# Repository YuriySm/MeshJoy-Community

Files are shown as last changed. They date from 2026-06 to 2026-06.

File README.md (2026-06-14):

# MeshJoy

*[🇺🇦 Ukrainian / Українська версія](README.uk.md).*

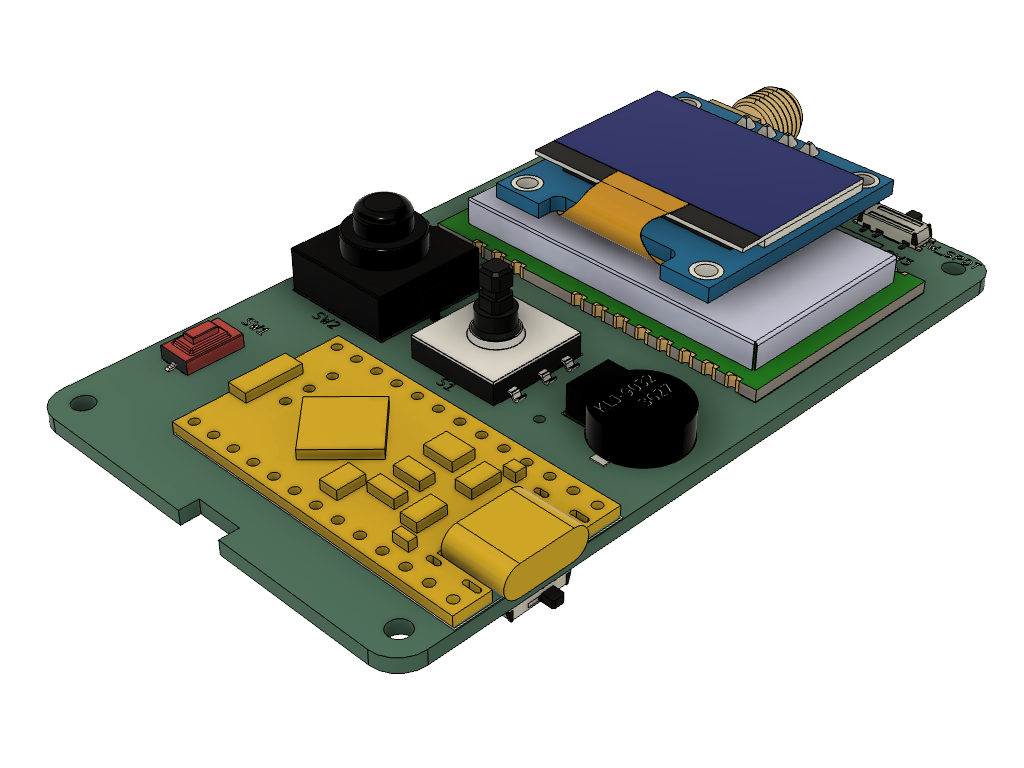
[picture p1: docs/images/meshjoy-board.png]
MeshJoy board


A portable **Meshtastic / Meshcore** radio device with up to **1 W LoRa** output power and **3–4 days** of battery life.

Built for hikers, radio amateurs, and anyone who needs communication without the internet.

> Status: v0.2.2 assembled and tested.

## Features

- **Joystick + OLED screen** — convenient menu navigation via a 4-way joystick with push-to-select.
- **Physical power button** — combined mechanical/electronic power control.
- **GPS switch** — GPS can be fully disabled in software *or* with a hardware switch on the case.
- **GPS navigation** (optional) — Ebyte E108-GN02D receiver reports coordinates at configurable intervals to the public Meshtastic network or only to selected contacts. The receiver sleeps between intervals to save power.
- **Buzzer** — sound notifier pre-installed on the board.
- **Expandable** — optional vibration motor; accessible reset button and visible status LEDs without opening the case.
- **Built-in charger** — charging managed by the microcontroller; over-discharge protection via the battery BMS.

## Battery options

| Battery | Capacity | GPS |
|---|---|---|
| LiPo 103450 | 2000 mAh | Yes |
| Li-Ion 18650 | 3400 mAh | Yes |
| Li-Ion 18650 ×2 | 6800 mAh | No |

## Specifications

| | |
|---|---|
| LoRa radio | Ebyte E22-400M30S, 1 W |
| Microcontroller | ProMicro nRF52840 |
| GPS | Yes (optional) |
| Bluetooth | Yes (~2 m range) |
| Wi-Fi | No |
| Battery | 2000 mAh (2400–6800 mAh) |
| Charge current | ~300 mA |
| Battery life | 3–4 days (no GPS, 2 Ah battery) |
| Charge time | ~7 hours (2 Ah battery) |
| Water resistance | None |
| Size | 49 × 96 × 27 mm (W × H × D) |

## Technical notes

- **Processor:** nRF52840 (ProMicro / SuperMini clone) — low-power, Bluetooth, no Wi-Fi. Built-in LiPo charge controller and 2 LEDs. Reset button broken out on the main board.
- **LoRa:** Ebyte E22-400M30S, 1 W @ 433 MHz. At 5 V it reliably delivers 1–1.2 W.
- **Antenna connector:** SMA female mounted parallel to the board surface — easier to solder and to fit in a small case.
- **Power:** Runs from a 1S (3.7 V) battery or USB-C. An XL6380 boost converter supplies 5 V for the LoRa module. Peak draw during transmit is up to ~1.5 A; average consumption with a test transmission every 5 min was ~65 mW.
- **Power switch:** Combined mechanical/electronic — a physical button drives a MOSFET that switches battery current (a plain micro-switch can't handle the ~1.5 A peak).
- **Joystick:** 4 positions + press; soldered as SMD. The device name comes from "Mesh" + "joystick".
- **Screen:** Standard 0.96" OLED (GND-VCC pinout).
- **External device control:** 2 power MOSFETs switch ground — one for the buzzer, one broken out for a vibration motor or GPS control. A slide switch also cuts +5 V for low-power peripherals (e.g. fully powering off GPS).
- **Board:** Custom-designed, using the standard `nrf52_promicro_diy_tcxo` Meshtastic pinout.

## Enclosure

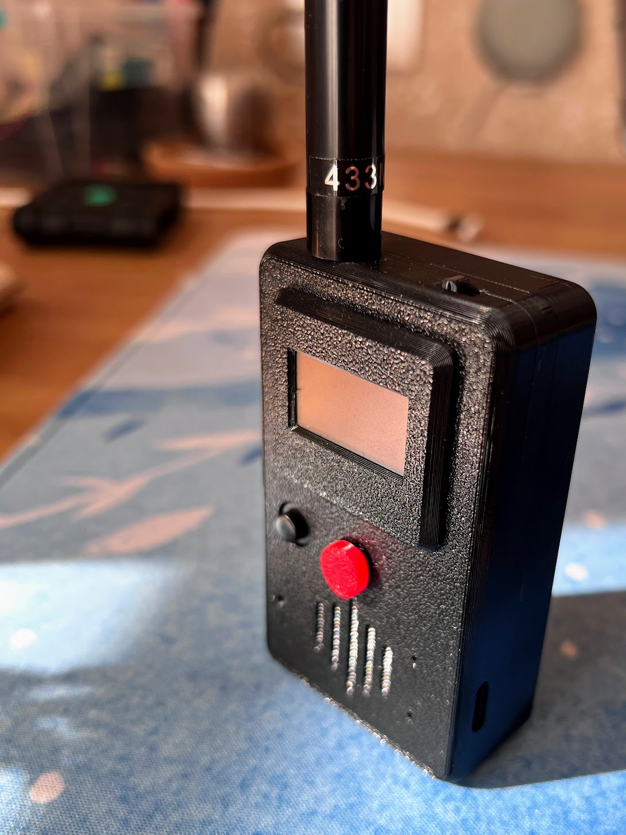
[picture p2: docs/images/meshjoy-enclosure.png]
MeshJoy enclosure


The case was designed from scratch in Fusion 360 and will be **free to download and modify**. It is optimized for fast, support-free 3D printing (PETG). The screen bezel snaps into the top cover without glue; halves are joined with M2 screws (no nuts) and the board is held by integrated standoffs. Mounting for the GPS module is included.

## Links

- Website: https://meshjoy.com.ua/
- Technical details: https://meshjoy.com.ua/technical-details/
- Telegram discussion group: https://t.me/MeshJoy
- Contact the author: https://t.me/Yura_e2c77f35

## License

These materials are licensed under [CC BY-NC-SA 4.0](https://creativecommons.org/licenses/by-nc-sa/4.0/) (Attribution — NonCommercial — ShareAlike).

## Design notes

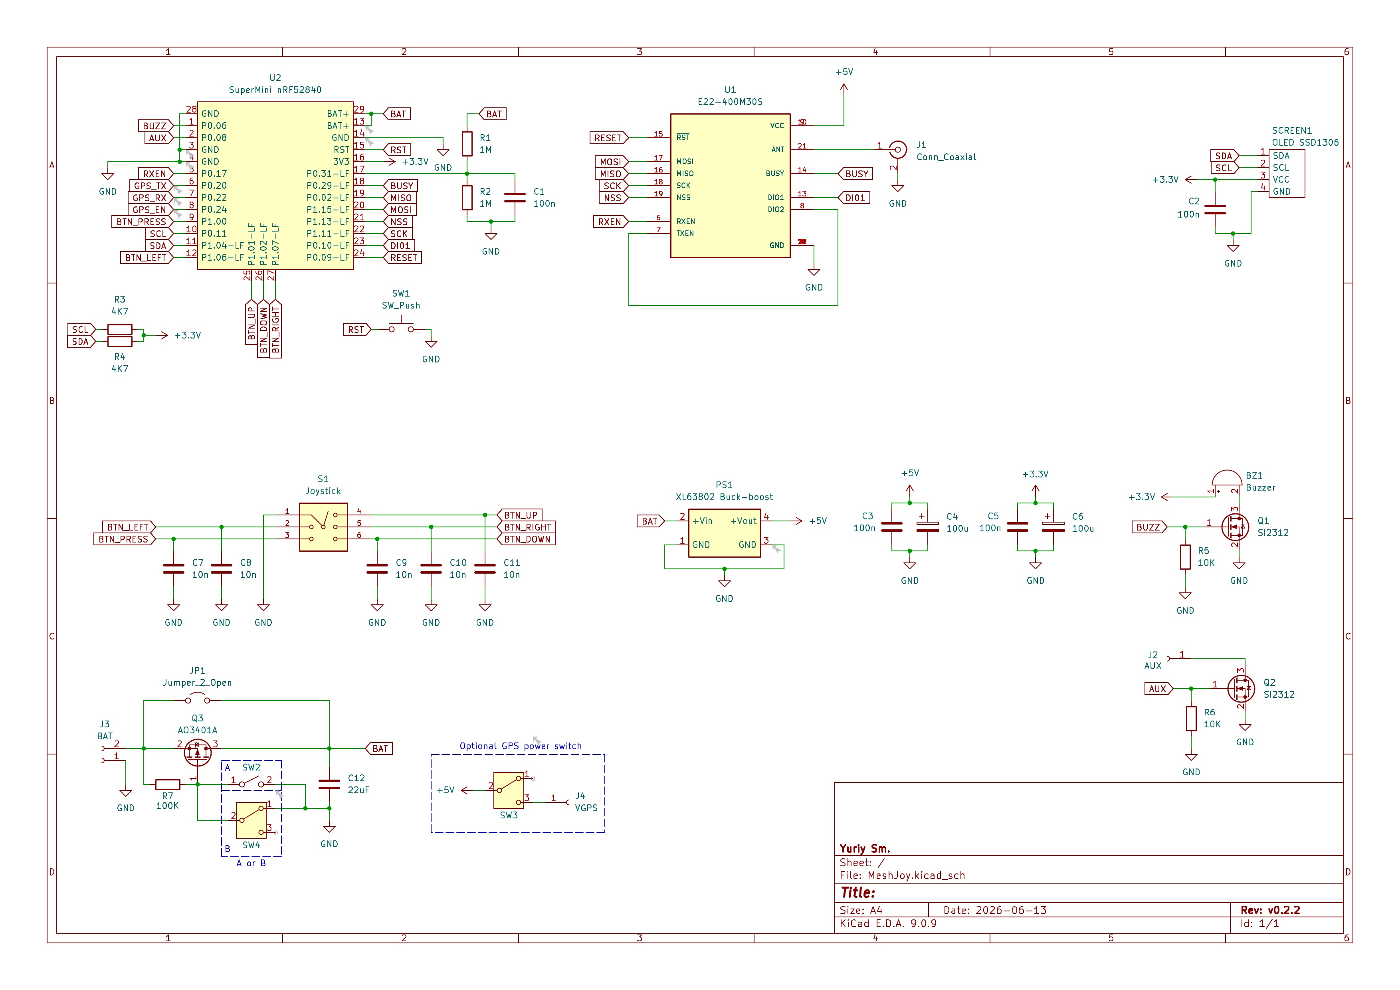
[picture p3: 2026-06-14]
schematic/MeshJoy-v0.2.2-Schematic.png

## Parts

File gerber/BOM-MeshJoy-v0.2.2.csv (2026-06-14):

Comment | Designator | Footprint | LCSC | Quantity
100K | R7 | R_0603_1608Metric_Pad0.98x0.95mm_HandSolder | C25803 | 1
100n | C1,C2,C3,C5 | C_0603_1608Metric_Pad1.08x0.95mm_HandSolder | C14663 | 4
100u | C4,C6 | CP_EIA-3528-15_AVX-H_HandSolder | C16133 | 2
10K | R5,R6 | R_0603_1608Metric_Pad0.98x0.95mm_HandSolder | C25804 | 2
10n | C10,C11,C7,C8,C9 | C_0603_1608Metric_Pad1.08x0.95mm_HandSolder | C57112 | 5
1M | R1,R2 | R_0603_1608Metric_Pad0.98x0.95mm_HandSolder | C22935 | 2
22uF | C12 | C_0603_1608Metric_Pad1.08x0.95mm_HandSolder | C59461 | 1
4K7 | R3,R4 | R_0603_1608Metric_Pad0.98x0.95mm_HandSolder | C23162 | 2
AO3401A | Q3 | SOT-23 | C15127 | 1
SI2312 | Q1,Q2 | SOT-23 | C20917 | 2
E22-400M30S | U1 | XCVR_E22-900M30S_manual_solder |  | 1
OLED SSD1306 | SCREEN1 | SSD1306 |  | 1
SW_Push | SW1 | SW_3x4x2_SMD |  | 1
SW_SPST | SW2 | button_12x12 |  | 1
Joystick | S1 | 5_Way_Switch_10mm |  | 1
SuperMini nRF52840 | U2 | SuperMini_nRF52840_AH_USBup |  | 1
ANT | J1 | SMA_Samtec_SMA-J-P-H-ST-EM1_EdgeMount |  | 1
Buzzer | BZ1 | Buzzer_9032 |  | 1
XL63802 Buck-boost | PS1 | XL63802-Buck-boost |  | 1
BAT | J3 | JST_PH_S2B-PH-K_1x02_P2.00mm_Horizontal |  | 1
-VAUX | J2 | PinHeader_1x01_P2.54mm_Vertical |  | 1
+VGPS | J4 | Pin_D0.7mm_L6.5mm_W1.8mm_FlatFork |  | 1
AUX | SW3 | SW_SPDT_PCM12 |  | 1
PWR | SW4 | SW_SPDT_PCM12 |  | 1
Jumper_2_Open | JP1 | SolderJumper-2_P1.3mm_Open_Pad1.0x1.5mm |  | 1

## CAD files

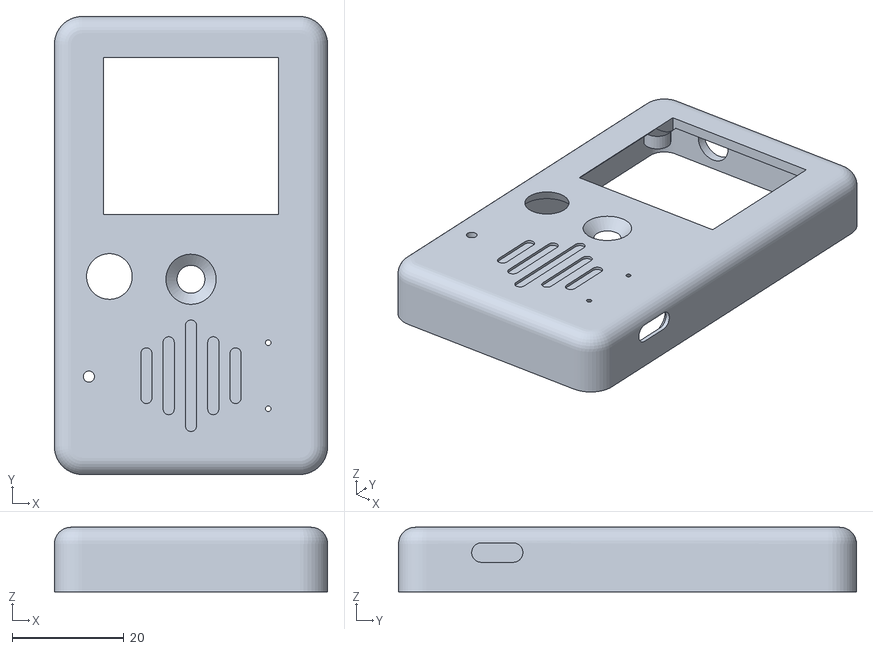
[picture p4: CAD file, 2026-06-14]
enclosure/meshjoy-v02-top-case.stl
49.0 x 82.1 x 11.6

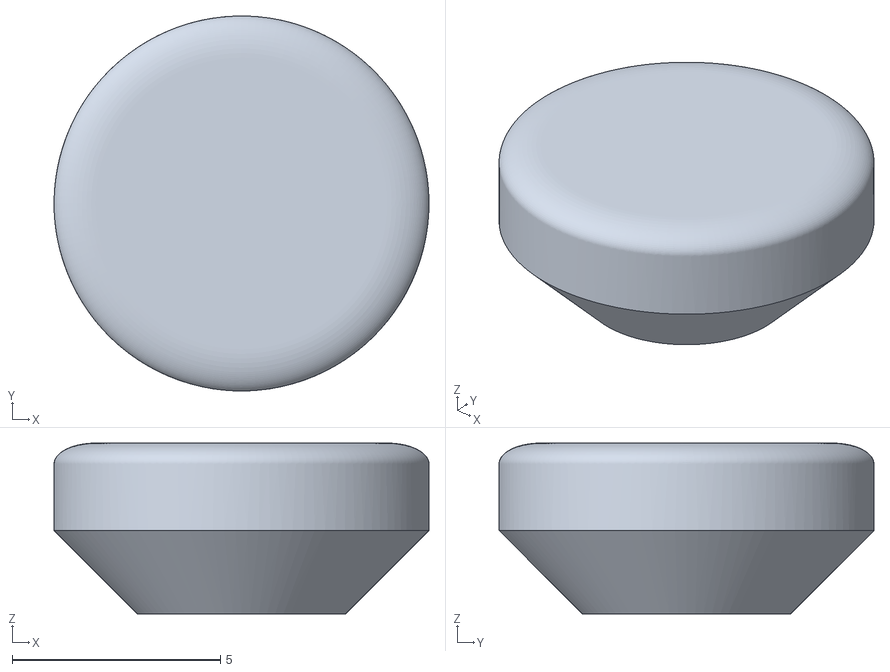
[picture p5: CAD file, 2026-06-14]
enclosure/meshjoy-v02-joystick-cap.stl
9.00 x 9.00 x 4.10

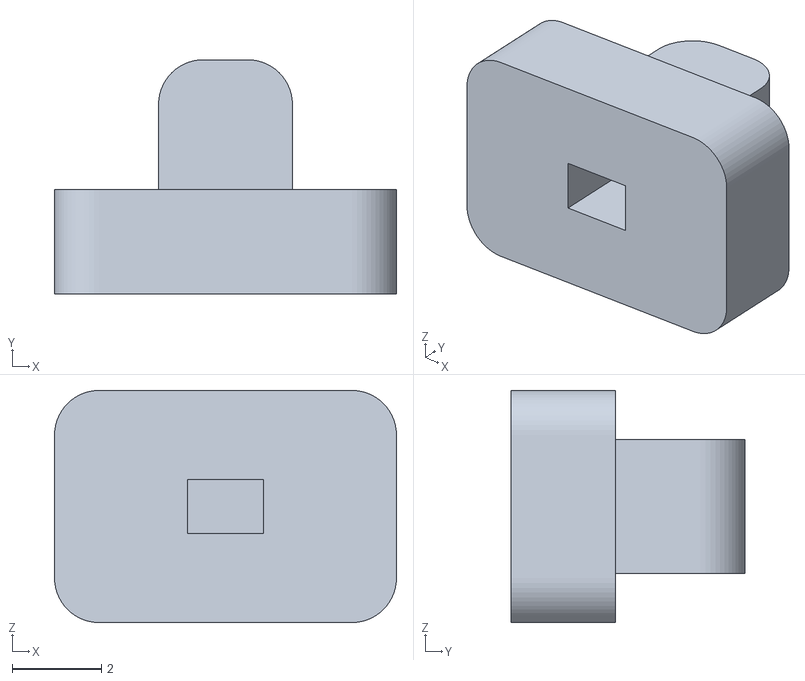
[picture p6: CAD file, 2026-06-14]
enclosure/meshjoy-v02-aux-switch-cap.stl
7.66 x 5.25 x 5.20

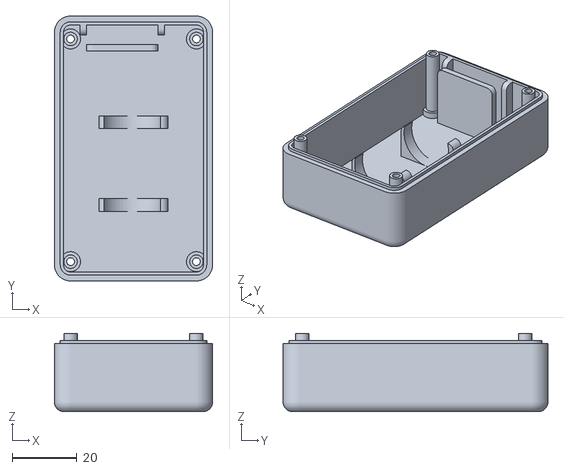
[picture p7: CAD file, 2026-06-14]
enclosure/meshjoy-v02-bottom-case-1x-18650.stl
49.0 x 82.1 x 24.3

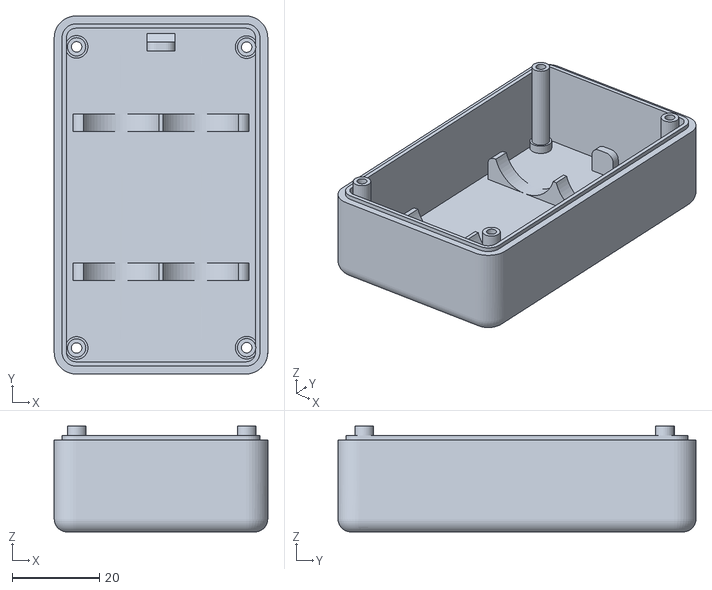
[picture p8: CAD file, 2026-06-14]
enclosure/meshjoy-v02-bottom-case-2x-18650.stl
49.0 x 82.1 x 24.3

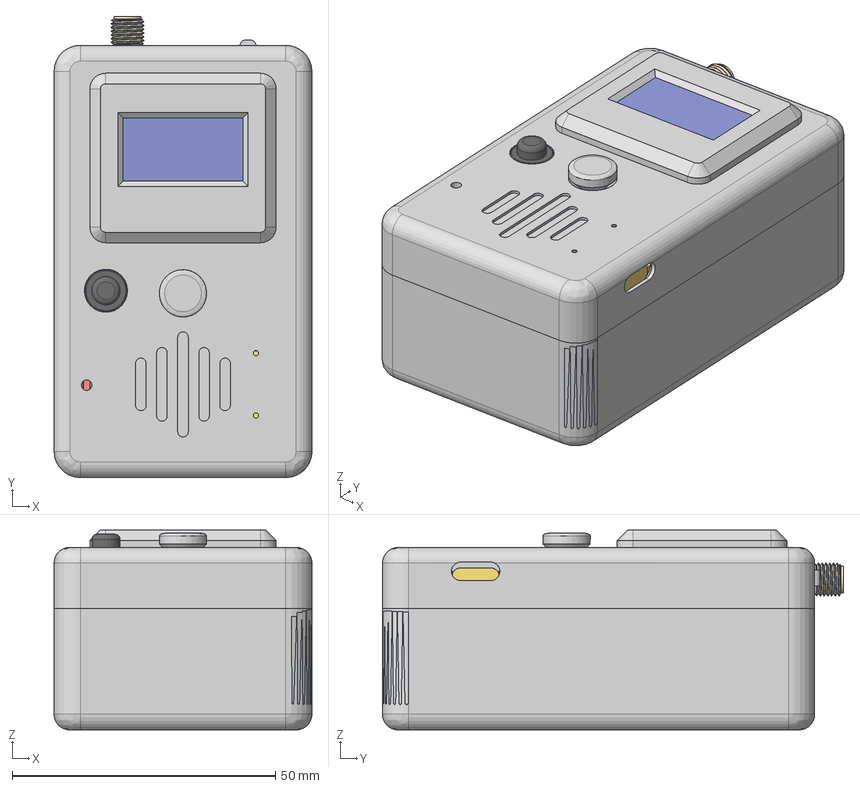
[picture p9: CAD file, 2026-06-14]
enclosure/meshjoy-case-v02-fusion-360-v21.step
49.0 x 87.6 x 38.0 mm
promicronrf52840
board
screen
pin_header
soldering
smd_capacitor
smd_capacitor (1)
914_smd_resistor
472_smd_resistor x 3
t4_smd_diode
smd_capacitor (2)
smd_capacitor (3)
smd_capacitor (4)
smd_capacitor (5)
smd_capacitor (6)
472_smd_resistor (1)
SOT-23_XC6206 v3
smd_capacitor (7)
flat_cable
TactileButton(6x3,5mm)_SMD
5-WayTactileButton10mmSMD
YT-CB1212-112D
E22-900M30S--3DModel-STEP-418109
SMA_Samtec_SMA-J-P-H-ST-EM1_EdgeMount
SW_SPDT_PCM12 x 2
C_0603_1608Metric x 10
CP_EIA-3528-15_AVX-H x 2
R_0603_1608Metric x 7
SOT-23 x 3
cube_26x13x3p3mm
JST_PH_S2B-PH-K_1x02_P2.00mm_Horizontal
MeshJoy_silkscreen
MeshJoy_silkscreen_1
MeshJoy_PCB
MeshJoy v0.2 Top Case
MeshJoy v0.2 AUX switch cap
MeshJoy v0.2 Screen Lid
MeshJoy v0.2 Bottom Case
MeshJoy v0.2 GPS holder
MeshJoy v0.2 Joystick Cap
MeshJoy v0.2 Bottom Case 1x 18650
MeshJoy v0.2 Bottom Case 1x 21700
MeshJoy v0.2 Bottom Case 2x 18650

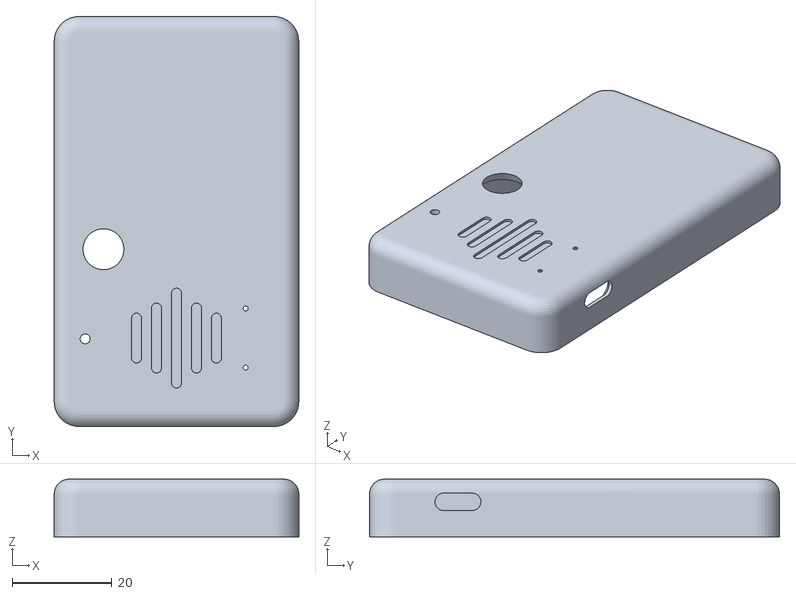
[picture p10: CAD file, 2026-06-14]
enclosure/meshjoy-v02-top-case-no-screen.stl
49.0 x 82.1 x 11.6

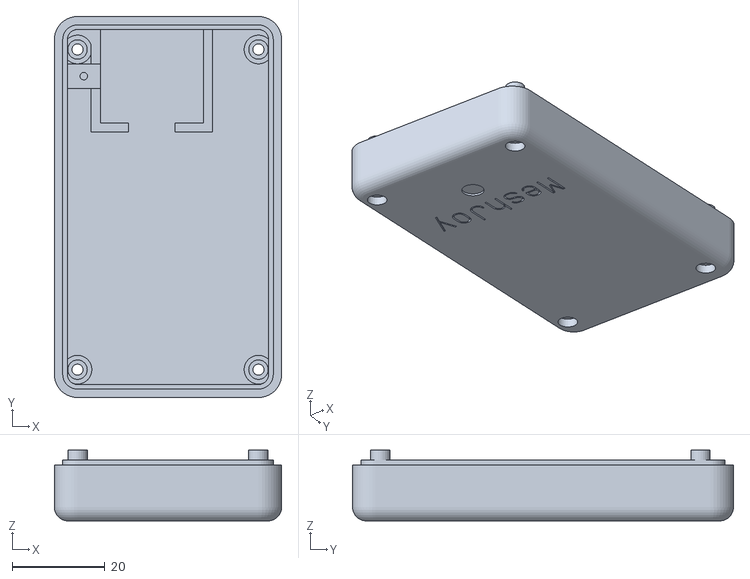
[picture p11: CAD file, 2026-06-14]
enclosure/meshjoy-v02-bottom-case.stl
49.0 x 82.1 x 15.3

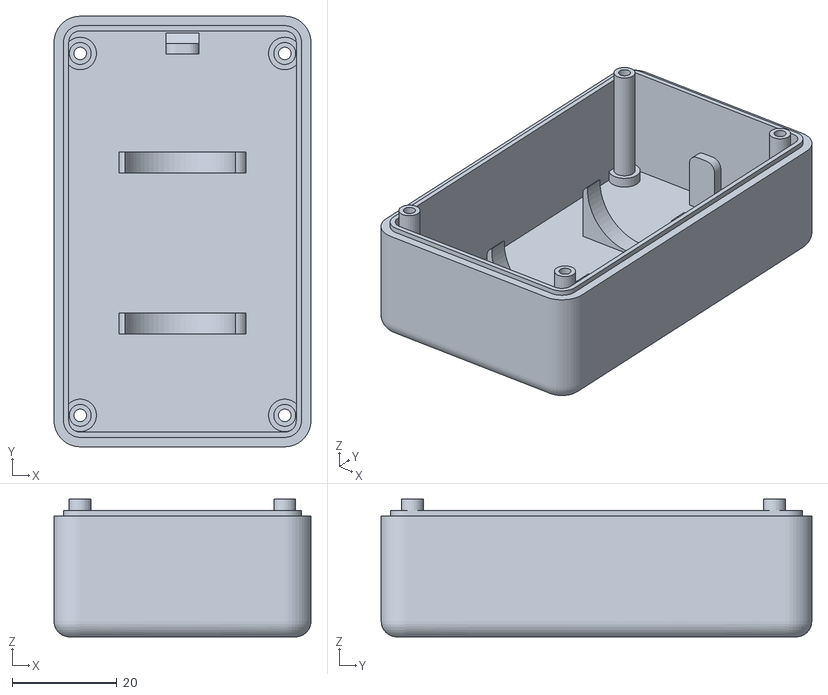
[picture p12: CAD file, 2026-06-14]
enclosure/meshjoy-v02-bottom-case-1x-21700.stl
49.0 x 82.1 x 26.3

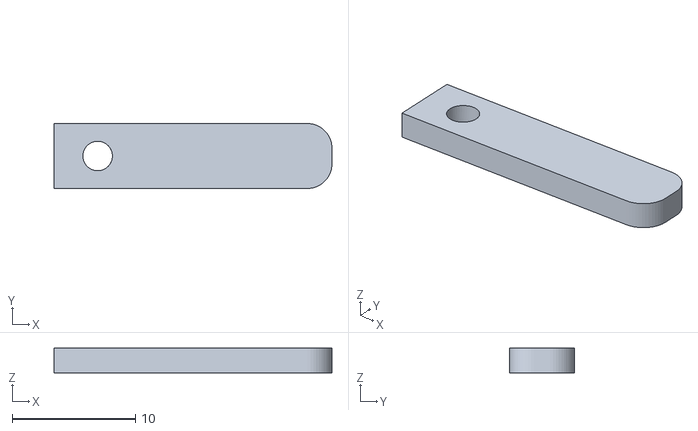
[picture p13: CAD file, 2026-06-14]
enclosure/meshjoy-v02-gps-holder.stl
22.6 x 5.28 x 2.00

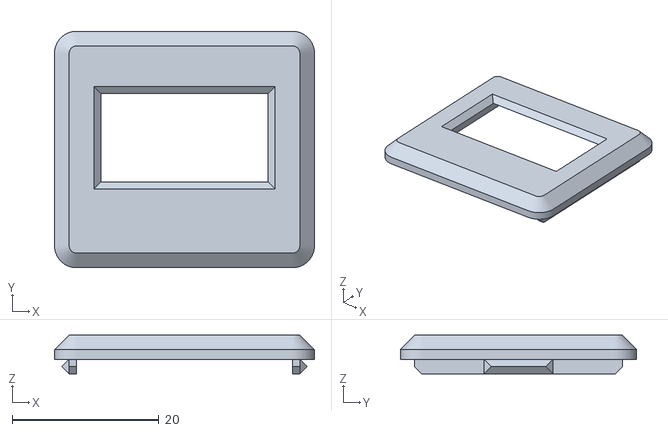
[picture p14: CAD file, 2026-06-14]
enclosure/meshjoy-v02-screen-lid.stl
35.4 x 32.2 x 5.30

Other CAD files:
enclosure/meshjoy-v02-joystick-cap-tight.stl
enclosure/meshjoy-v02-case-fusion-v20.f3z

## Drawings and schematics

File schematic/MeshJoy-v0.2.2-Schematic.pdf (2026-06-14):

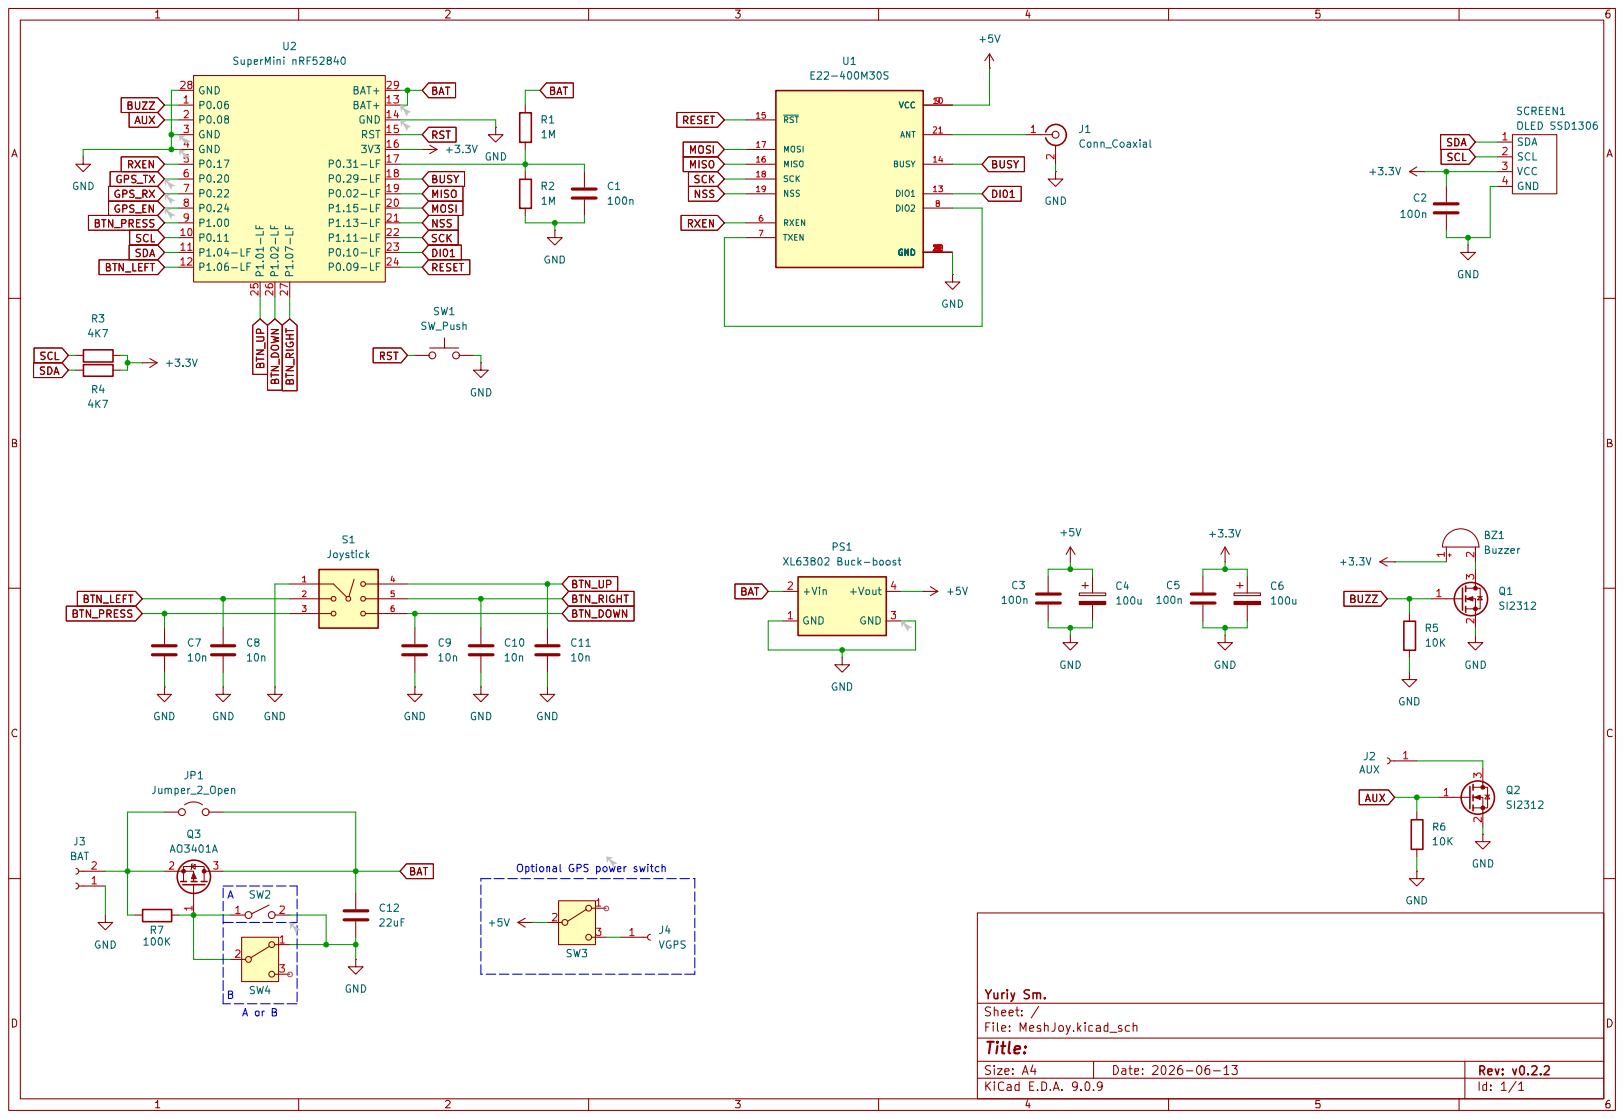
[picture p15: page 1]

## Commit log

2026-06-14 Create initial project layout with firmware, enclosure, gerber, schematic directories and add default .gitignore
    [BOM-MeshJoy-v0.2.2.csv, meshjoy-case-v02-fusion-360-v21.step, meshjoy-v02-aux-switch-cap.stl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]
2026-06-14 Add README (EN/UK), board images, and CC BY-NC-SA 4.0 license
    - README.md and README.uk.md describing the MeshJoy device, specs,
    technical notes, and enclosure
    - docs/images: board and enclosure renders
    - LICENSE: CC BY-NC-SA 4.0 full text
